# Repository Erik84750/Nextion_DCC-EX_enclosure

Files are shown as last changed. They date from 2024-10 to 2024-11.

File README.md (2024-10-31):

# Nextion_DCC-EX_enclosure
Files for 3D printing of DCC-EX_Nextion-controller enclosures

1. INTRODUCTION:

  This repository serves as a source for 3D printable enclosures for the Nextion DCC-EX project on this location: https://github.com/normhal?tab=repositories
  This repository contains the .stl files for 
  
  A. 3.2", 3.5", 4.3" and 5" Nextion display enclosures for custom-made pcb + charger/UPS unit with 2x 18650 Li-Ion batteries
  
  B. 3.2", 3.5" and 4.3" Nextion display enclosures for Wemos_ESP8266_18650 Li-Ion single battery unit or Wemos_ESP32_18650 single battery unit modules

  C. 3.2", 3.5" and 4.3" Nextion display enclosures for Raspberry Pico

2. FEATURES for version A

  a. the enclosure contain the necessary mounting tabs for a master-PCB and a 2x 18650 Li-Ion battery/charger/UPS.

  b. the enclosure provides the proper mounting points for the applicable Nextion display

  c. holes are provided for an ON/OFF switch and a jack 3-pole receptacle for wired tethering (RX, TX, GND)

  d. an opening for USB-C charging connection

  e. openings for a rotary encoder and for 2 LED's (batteries charging and batteries charged).

3. HARDWARE REQUIREMENTS for version A:

  a. the master pcb can be manufactured from the provided Gerber files. Beware of the mounting hole dimensions and psotions when making your own PCB).
  See https://github.com/Erik84750/Nextion_DCC-EX_master-pcb
  
  b. the battery holder and charging circuitry are contained on one PCB with specific mounting holes. Use this reference as a source: https://tinyurl.com/5b3ys9ak
    Make sure the 5V DC output version is used. See picture below at bottom for modification instructions for this charger/UPS module.
    Marked "1": desolder the 2 SMD LED's and replace with wiring to the two 3mm LED's on the front panel; wiring is "common positive". 
    This means that the LED anodes both are connected together to the positive pad, and that the LED cathodes are sperarately connected each to their respective negative pad. 
    Marked "2": cut this LED.
    
  c. the rotary encoder needs to be  the basic version (no pcb attached) due to space constraints:
  
  rotary encoder wiring
  
  Wiring should preferably include a 10k pull-up resistor for OutA, OutB and Switch (D) and connected to +5V or +3V

  Rotary Encoder top view - basic wiring

  d. the 2 enclosure front LED's are 3mm. See drawing right below for instructions on cutting/removing/resoldering 3mm LED's on casing front. "1" shows LED's to be removed from PCB. "2" shows LED to be cut to minimize idle current flow.
  The LED's power is common anode; the LED cathodes need a 1 to 10k 1/8W resistor before connection to their respective negative supply poles. Recommended red for charging, blue for charged.

  e. the external tethering jack 3.5mm receptacle needs to be this version as a reference: https://tinyurl.com/3r4jh7u7

  f. for mounting the lid, Nextion display, PCB and battery charger these brass M3 heat-inserts: M3 OD 4.2mm length 3mm, and M3 OD 5mm length 5mm:
    https://tinyurl.com/fwtkpy7e

battery_charger_18560_UPS

4. 3D PRINTING REQUIREMENTS:

  a. A minimal printing bed surface of 260x240mm is necessary (ie Anycubic Vyper)
  
  b. it is recommended to use a bimetal titanium throat: https://tinyurl.com/mrxmm24h
  
  c. only use high quality PLA filament: due to the complexity of the model (overhangs, holes, ..). For example: Spectrum, to a lesser extent eSun..
     Prussa filament is very good but expensive.
    Suboptimal results were obtained with Fiberlogy, and of course house brands or knock-offs which are off-limits. Not recommended: Azurefilm, Polymaker, Formfutura,..
    
  d. Some basic printer settings: Retraction = 9mm, Printing speed = 65mm/sec, no support structure, filling thickness 60% (2mm line distance),
    Filling pattern: cubic, Layer height 0.1mm, Wall thickness 0.8mm, Number of wall lines: 2, Print temp (Spectrum): 205°C, Bed temp: 60°C

  e. Some very good guides on Anycubic Vyper settings: https://tinyurl.com/2z6cprxj and https://tinyurl.com/yr662upk

5. Hardware requirements for version B:

Either Wemos with ESP8266 with 18650 Li-Ion battery module or Wemos with ESP32 with 18650 Li-Ion battery unit, built-in.

Wemos_ESP8266 connections: rotary encoder: "Switch" to D1, "Clock" to D7, "Data" to D6. Others: Nextion TX to D2, RX to D5. Hardware RX and TX: as noted on the PCB.

Wemos_ESP32 connections: self-explanatory on the PCB silkscreen. Rot. Enc. "Switch" to GPIO13, "Clk" to GPIO5, "Dat" to GPIO4. Nextion RX to GPIO3, TX GPIO17.

Wemos_ESP8266

Wemos_ESP32

6. Hardware modifications on the Wemos module for version B:

  a. (see picture below: marked in red "1") Remove the 1-pole ON/OFF switch and replace with an enclosure mounted single pole ON-OFF switch. Wiring: only the left solderpad (marked ON) and center solderpads to be connected to the switch!

  b. (see picture below: marked in red "2") Remove both SMD LED's (with red rectangle) and wire 2x 3mm LED's for enclosure top lid mounting; common positive to both LED's anodes, each LED "-" solder pad to the appropriate LED cathode

  c. Both the ESP8266 and ESP32 have a very similar component layout.

Wemos_mod_v1



Below: Wemos/ESP23/18650-battery module; the mod required to get 5V available for the Nextion display (IMPORTANT!! Take 5V from the "ON" tab of the ON/OFF switch!!), as well as "charging" and "charged" 3mm LED's on the enclosure, connections:

Nextion_Wemos_ESP32_battery-18650_v3

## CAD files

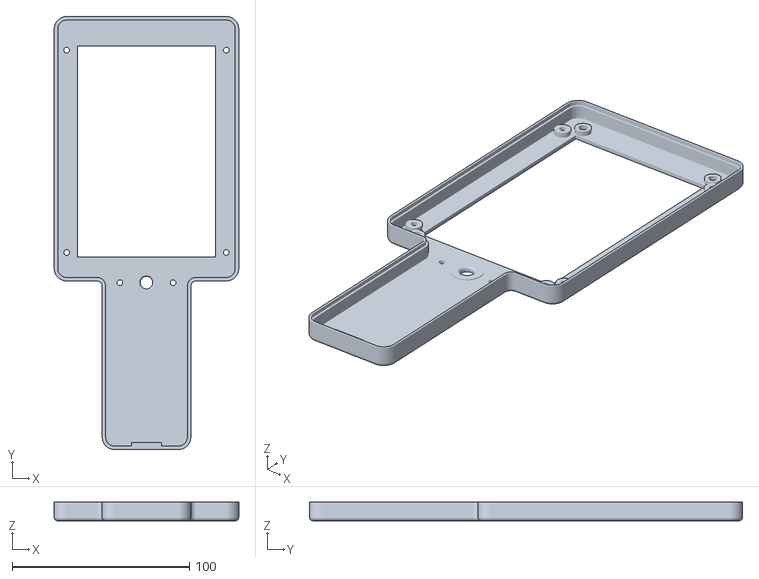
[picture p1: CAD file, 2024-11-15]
Nextion_5_inch_enclosure_v2_text-lid.stl
104.0 x 244.0 x 10.5

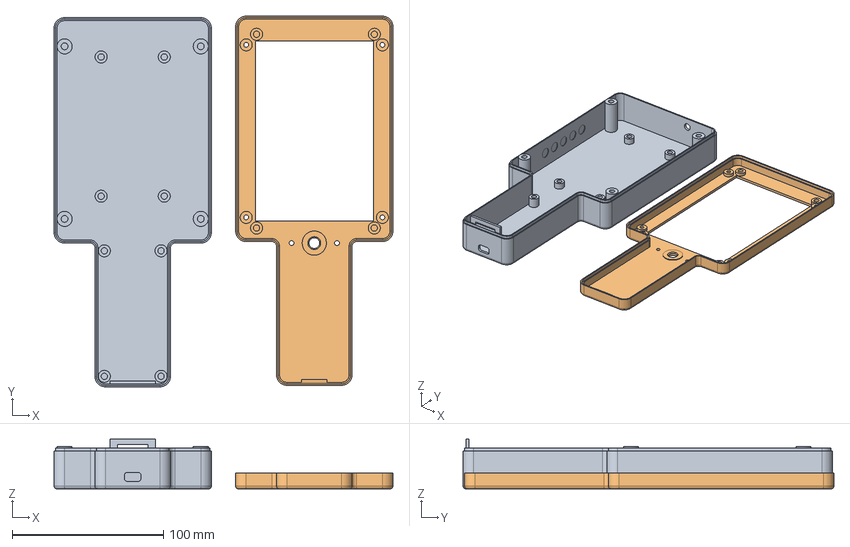
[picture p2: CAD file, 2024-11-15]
Nextion_5_inch_enclosure_v2_text.FCStd
224.0 x 245.0 x 33.0 mm
bottom
lid

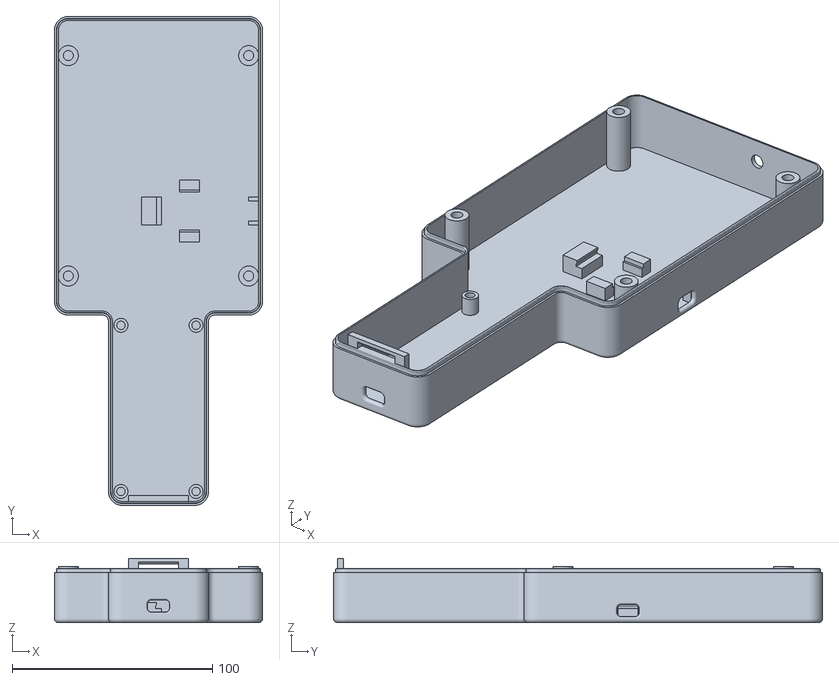
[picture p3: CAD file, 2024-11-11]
Nextion_5_inch_RPi_Pico_2-batt_v2_text-bottom.stl
104.0 x 244.0 x 32.0

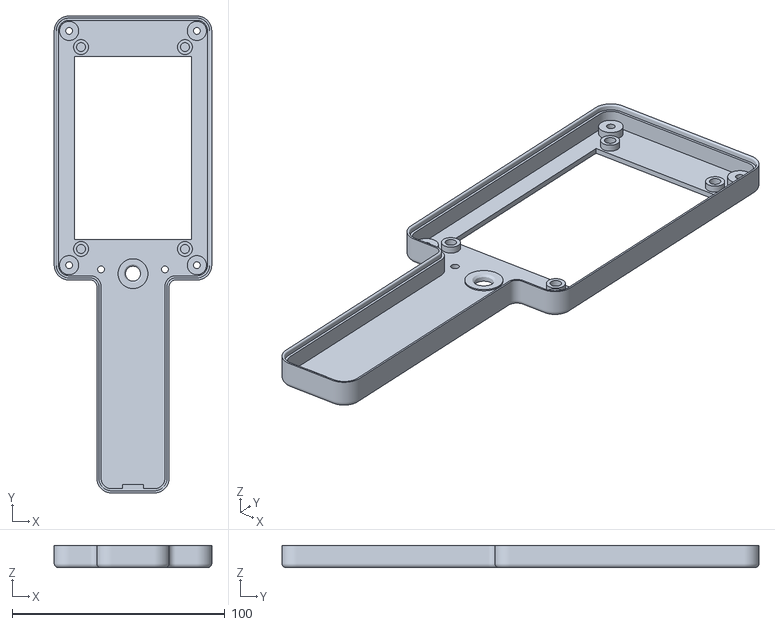
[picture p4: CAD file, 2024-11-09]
Nextion_3-5_inch_Wemos_ESP8266_v1_text-lid.stl
74.0 x 224.0 x 10.5

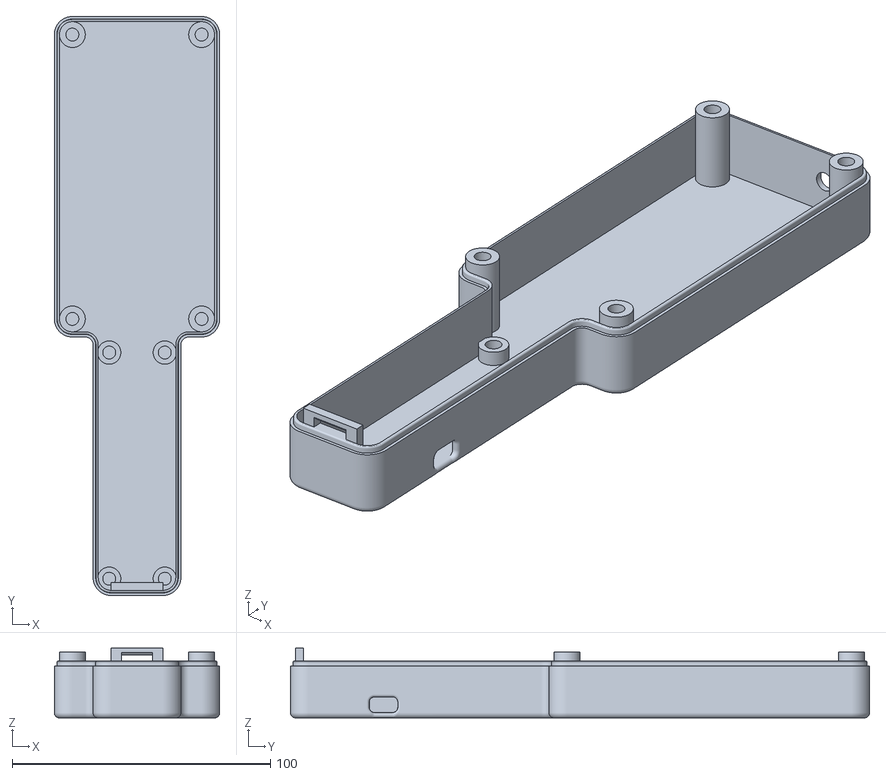
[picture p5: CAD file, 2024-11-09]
Nextion_3-2_inch_Wemos_ESP8266_v1_text-bottom.stl
64.0 x 224.0 x 27.0

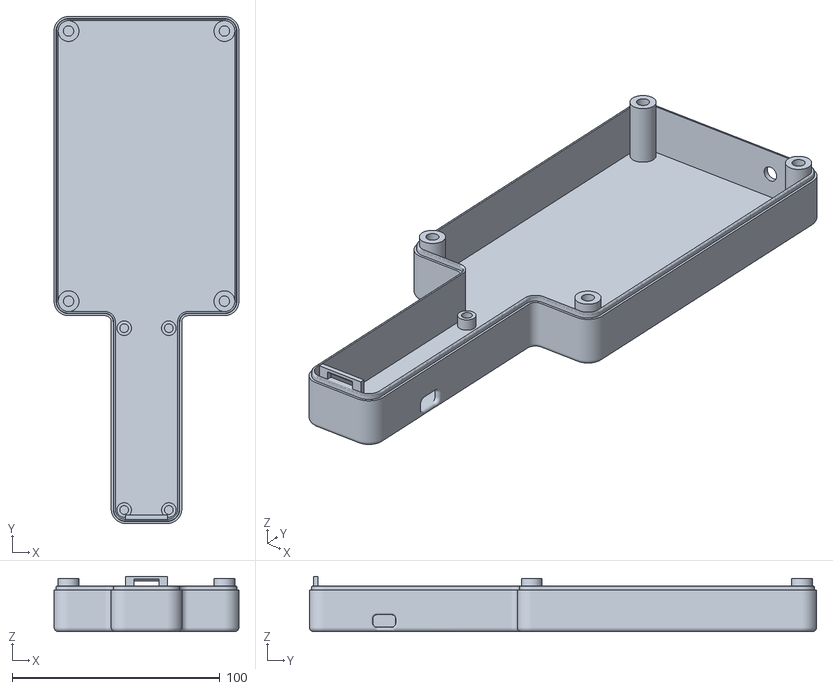
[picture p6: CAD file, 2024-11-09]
Nextion_4-3_inch_Wemos_ESP8266_v1_text-bottom.stl
89.0 x 244.0 x 26.5

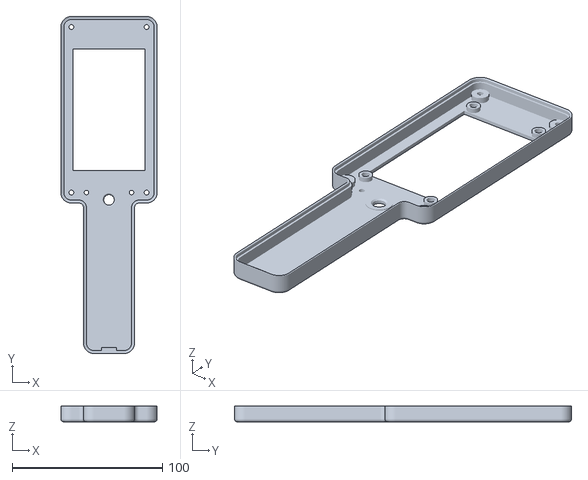
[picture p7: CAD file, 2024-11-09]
Nextion_3-2_inch_Wemos_ESP8266_v1_text-lid.stl
64.0 x 224.0 x 10.5

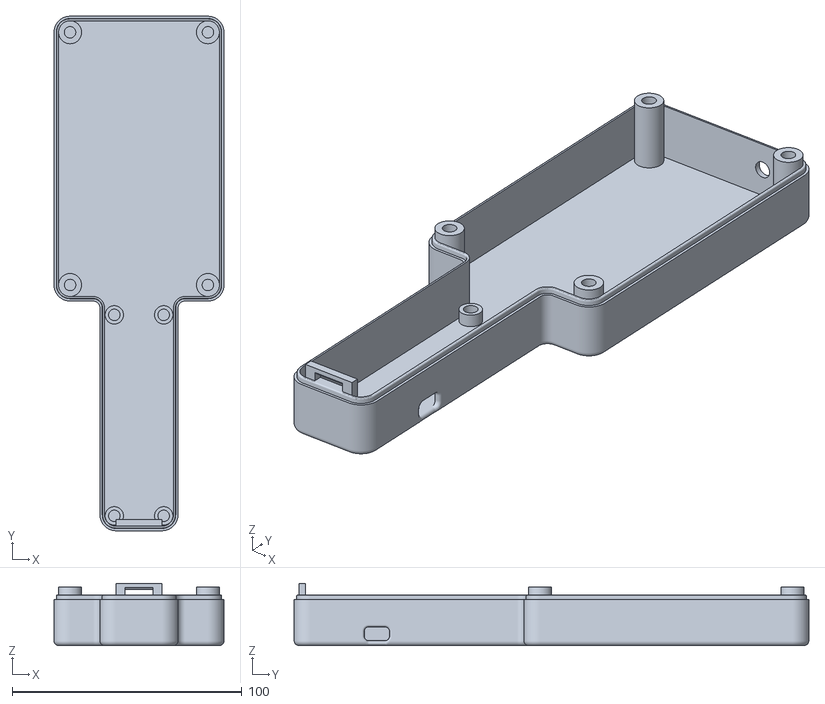
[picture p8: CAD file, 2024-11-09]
Nextion_3-5_inch_Wemos_ESP8266_v1_text-bottom.stl
74.0 x 224.0 x 27.0

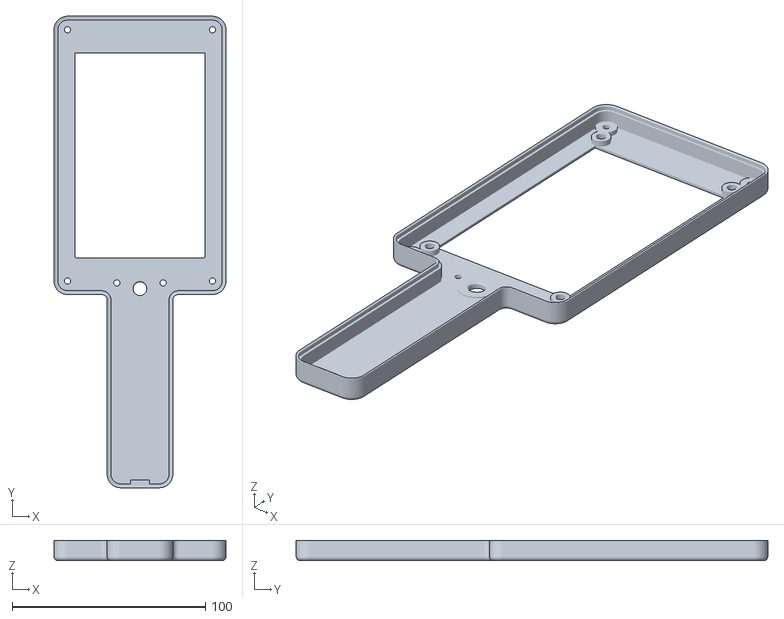
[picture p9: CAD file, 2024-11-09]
Nextion_4-3_inch_Wemos_ESP8266_v1_text-lid.stl
89.0 x 244.0 x 10.5

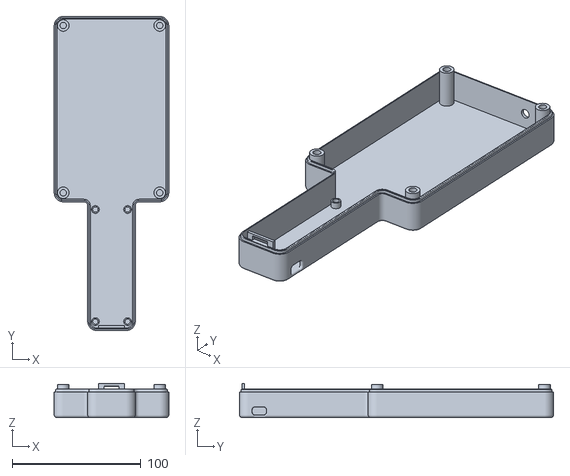
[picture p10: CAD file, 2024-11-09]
Nextion_4-3_inch_Wemos_ESP32_v1_text-bottom.stl
89.0 x 244.0 x 26.5

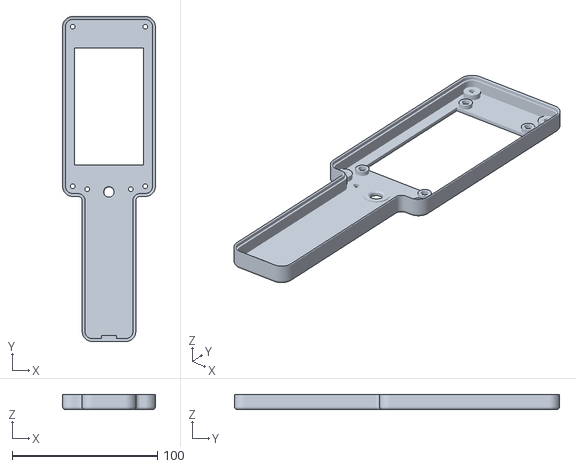
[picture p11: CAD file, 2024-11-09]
Nextion_3-2_inch_Wemos_ESP32_v1_text-lid.stl
64.0 x 224.0 x 10.5

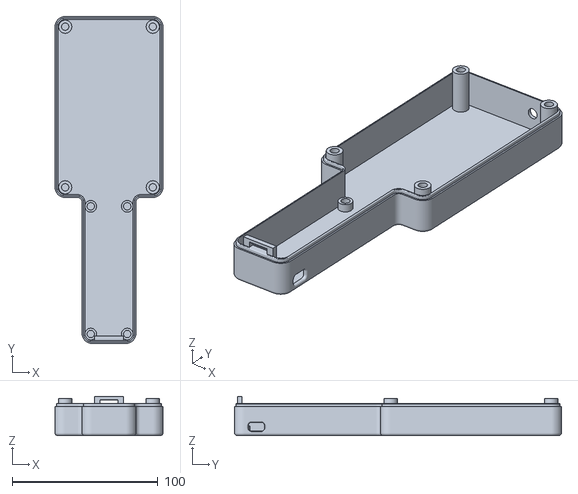
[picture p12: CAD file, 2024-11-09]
Nextion_3-5_inch_Wemos_ESP32_v1_text-bottom.stl
74.0 x 224.0 x 27.0

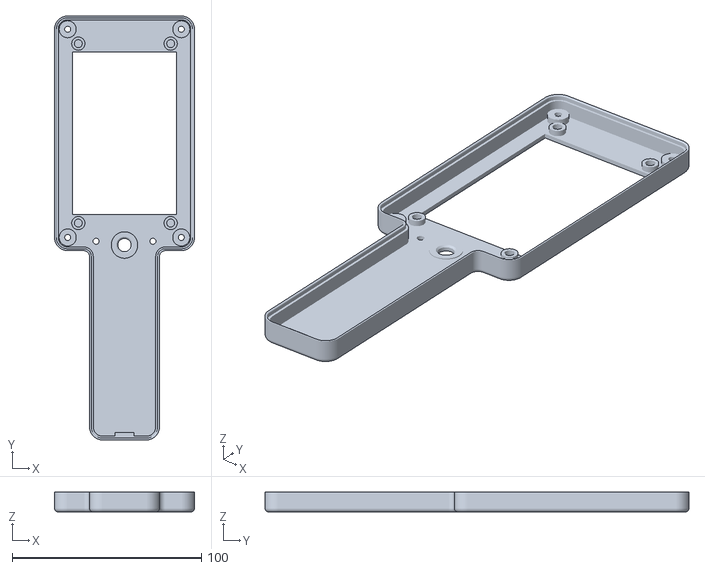
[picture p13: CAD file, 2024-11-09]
Nextion_3-5_inch_Wemos_ESP32_v1_text-lid.stl
74.0 x 224.0 x 10.5

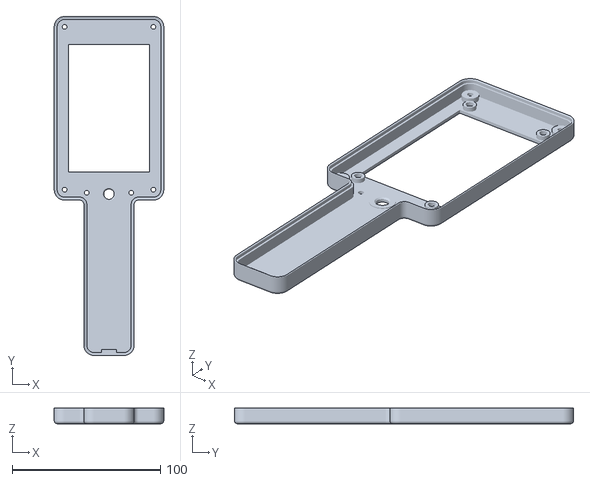
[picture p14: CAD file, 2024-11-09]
Nextion_3-5_inch_RPi_Pico_v1_text-lid.stl
74.0 x 229.0 x 10.5

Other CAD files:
Nextion_5_inch_RPi_Pico_2-batt_v2_text-lid.stl
Nextion_3-2_inch_Wemos_ESP32_v1_text-bottom.stl
Nextion_4-3_inch_Wemos_ESP32_v1_text-lid.stl
Nextion_3-2_inch_RPi_Pico_v2_text-lid.stl
Nextion_3-2_inch_RPi_Pico_v2_text-bottom.stl
Nextion_3-2_inch_enclosure_text-bottom.stl
Nextion_3-2_inch_enclosure_text-lid.stl
Nextion_3-5_inch_enclosure_text-bottom.stl
Nextion_3-5_inch_enclosure_text-lid.stl
Nextion_4-3_inch_RPi_Pico_2-batt_v2_text-bottom.stl
Nextion_4-3_inch_RPi_Pico_2-batt_v2_text-lid.stl
Nextion_4-3_inch_enclosure_v1_text-bottom.stl
Nextion_4-3_inch_enclosure_v1_text-lid.stl
